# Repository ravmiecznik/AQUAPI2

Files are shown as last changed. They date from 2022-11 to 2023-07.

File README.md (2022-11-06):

# AQUAPI2

## Aquarium controller based on RaspberryPi Zero2 and Arduino.<br>
The controller supports:<br>

* PH control with use of <a href=https://botland.store/gravity-temperature-sensors/5874-dfrobot-gravity-ph-analog-sensormeter-5903351243513.html>DFORBOT PROBE</a>
and CO2 injection system equipped with CO2 electric valve
<br>
<p  align=center>

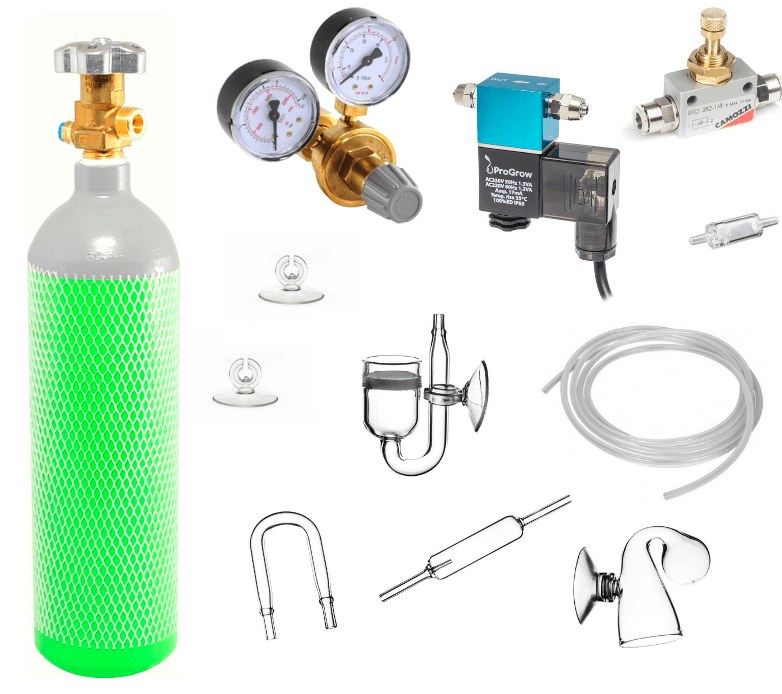
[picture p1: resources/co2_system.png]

</p>

* Temperature reading with DS12B20 digital thermometer sensor [<a href="https://www.circuitbasics.com/raspberry-pi-ds18b20-temperature-sensor-tutorial/">how to</a>] or any analog thermometer accessible via Arduino board

* Control devices and lighting with 8 channel Relay
<p align=center>
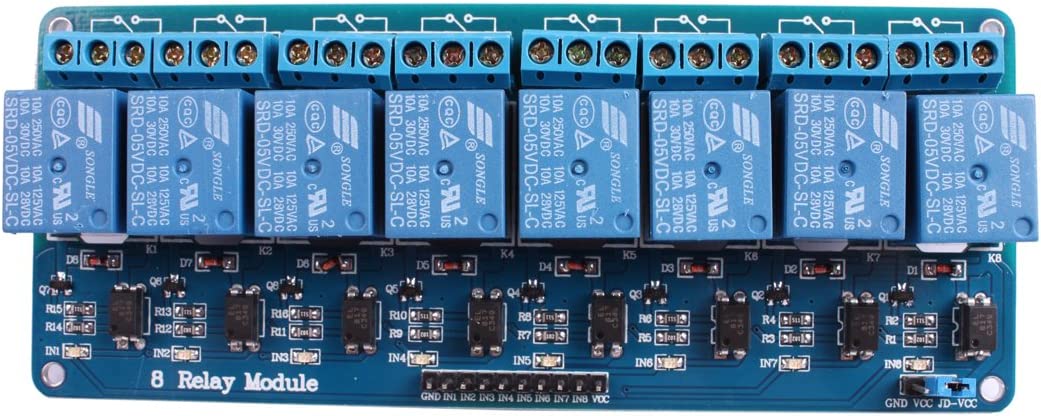
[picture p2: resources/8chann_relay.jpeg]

</p>

## Other components and software

* Arduino MINI PRO
<p  align=center>

</p>

* Arduino ISP programming done with RaspberryPI [<a href="https://learn.adafruit.com/program-an-avr-or-arduino-using-raspberry-pi-gpio-pins">Adafruit manual</a>]

* Plotly library <a href="https://plotly.com/python/">PLOTLY</a>
<p align=center>
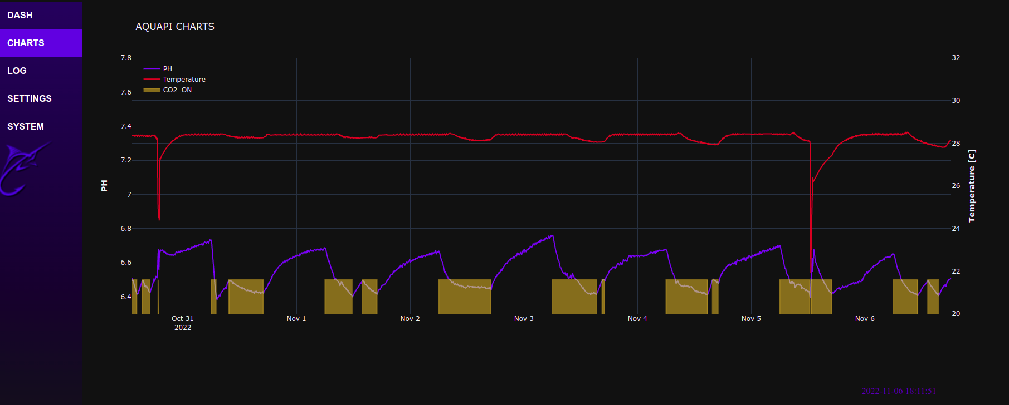
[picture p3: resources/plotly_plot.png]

</p>

* Circuit designed in Eagle [Version 0]

<p align=center>
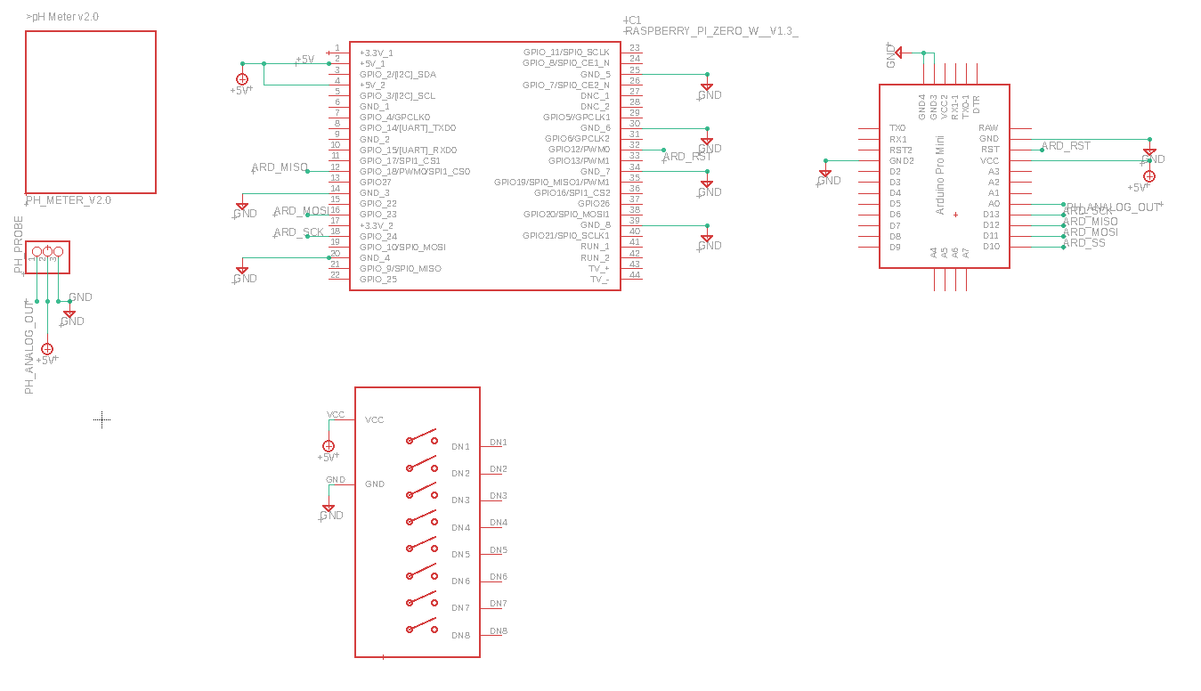
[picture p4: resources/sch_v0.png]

</p>

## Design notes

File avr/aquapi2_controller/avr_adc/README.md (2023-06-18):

### How to enable ADC
```C++
int main(void)
{
	Usart serial(get_usart_config());
	Serial = &serial;
	setup_stdout_for_printf();
	sei();

	{//auto remove temp variables in this scope

		bitfield8 adc_channels_ena;
		adc_channels_ena.b0 = 1;
		adc_channels_ena.b2 = 1;
        adc_channels_ena.b7 = 1;
		uint8_t samples_num = 3;
		Adc::enable_interrupt(adc_channels_ena, prescaler::div_128, vref::avcc_ext_cap, samples_num);
	}

	adc_results_s adc_results;
    while (true)
    {

    	Screen::clear();    //works when SCREEN is used on Linux
    	Screen::nl(20);
    	adc_results = Adc::get_adc_results();
    	printf("ADC1: %u\n\r", adc_results.adc0);
    	printf("ADC1: %u\n\r", adc_results.adc1);
    	printf("ADC2: %u\n\r", adc_results.adc2);
    	printf("ADC3: %u\n\r", adc_results.adc3);
    	printf("ADC4: %u\n\r", adc_results.adc4);
    	printf("ADC5: %u\n\r", adc_results.adc5);
    	printf("ADC6: %u\n\r", adc_results.adc6);
    	printf("ADC7: %u\n\r", adc_results.adc7);
    	printf("---------------------\n\r");

    	_delay_ms(500);
    }
}
```

### output 

```
---------------------
ADC1: 472
ADC1: 0
ADC2: 644
ADC3: 0
ADC4: 0
ADC5: 0
ADC6: 0
ADC7: 640
---------------------

```

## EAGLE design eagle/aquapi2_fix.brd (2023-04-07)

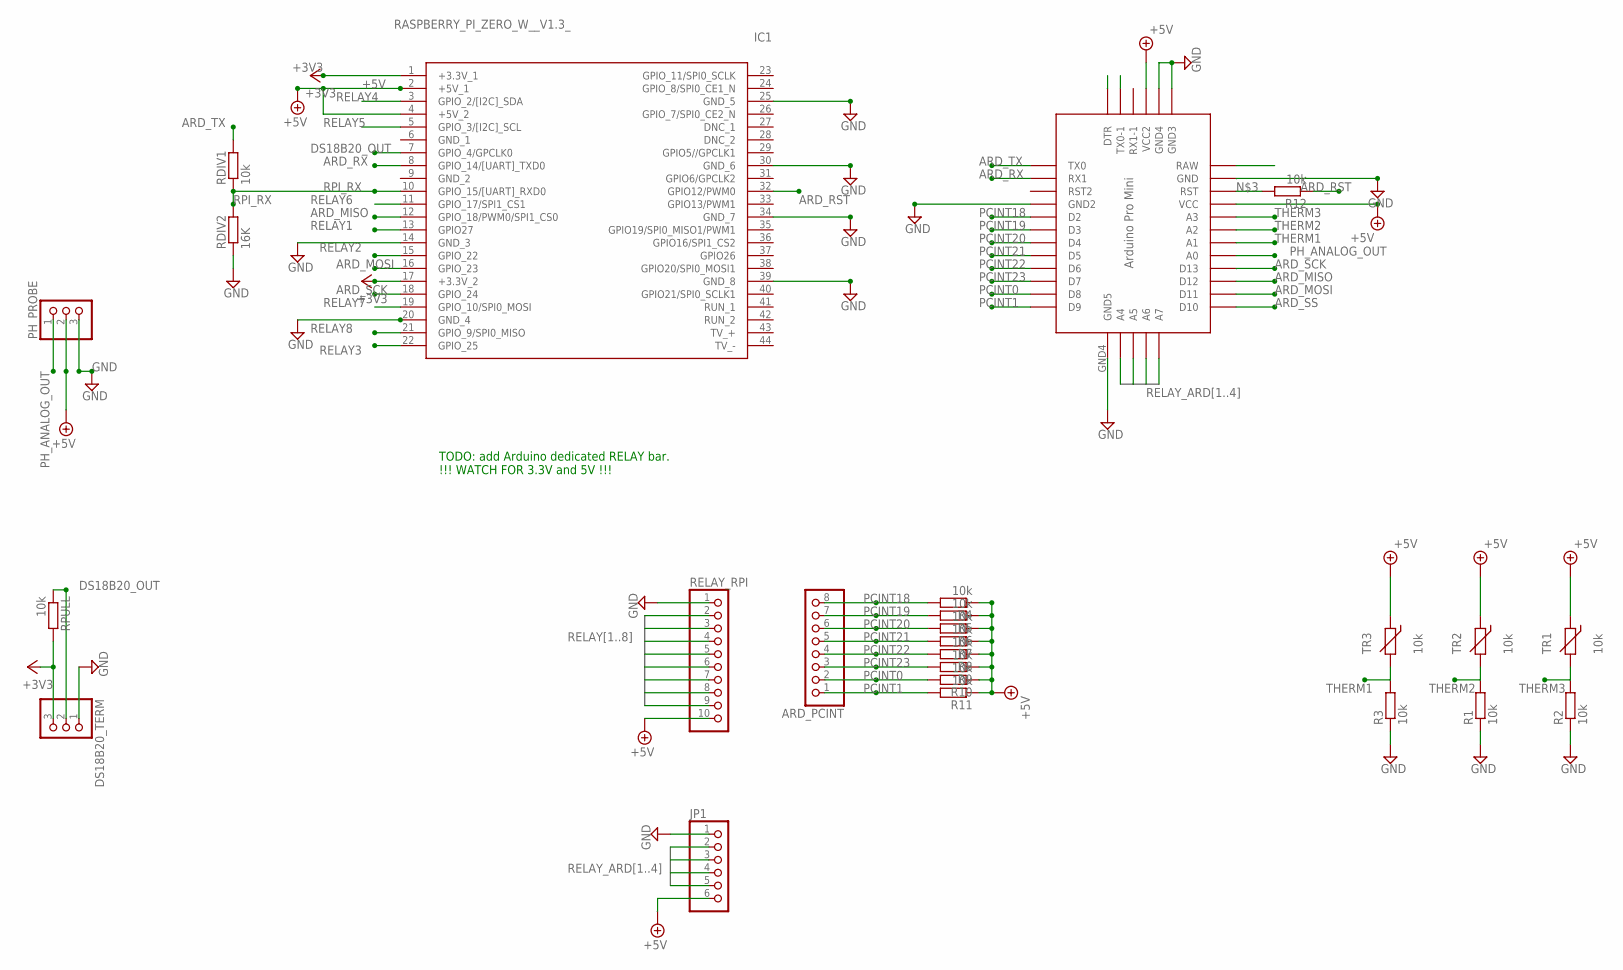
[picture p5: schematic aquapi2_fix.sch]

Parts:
ARD_PCINT: PINHD-1X8; 1X08
DS18B20_TERM: PINHD-1X3; 1X03
IC1: RASPBERRY_PI_ZERO_W__V1.3_; RASPBERRYPIZEROWV13
JP1: PINHD-1X6; 1X06
PH_PROBE: PINHD-1X3; 1X03
R1, R2, R3, R4, R5, R6, R7, R8, R9, R10, R11, R12: 10k; R0805
RDIV1: 10k; R0805
RDIV2: 16K; R0805
RELAY_RPI: PINHD-1X10; 1X10
RPULL: 10k; R0805
TR1, TR2, TR3: 10k; RS-2,5
U$2: PRO-MINI

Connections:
+3V3: DS18B20_TERM.3, IC1.1 (+3.3V_1), IC1.17 (+3.3V_2), RPULL.2
+5V: IC1.2 (+5V_1), IC1.4 (+5V_2), JP1.6, PH_PROBE.2, R4.1, R5.1, R6.1, R7.1, R8.1, R9.1, R10.1, R11.1, RELAY_RPI.10, TR1.1, TR2.1, TR3.1, U$2.VCC, U$2.VCC1 (VCC2)
ARD_MISO: IC1.12 (GPIO_18/PWM0/SPI1_CS0), U$2.D12
ARD_MOSI: IC1.16 (GPIO_23), U$2.D11
ARD_RST: IC1.32 (GPIO12/PWM0), R12.1
ARD_RX: IC1.8 (GPIO_14/[UART]_TXD0), U$2.RX1
ARD_SCK: IC1.18 (GPIO_24), U$2.D13
ARD_SS: U$2.D10
ARD_TX: RDIV1.2, U$2.TX0
DS18B20_OUT: DS18B20_TERM.2, IC1.7 (GPIO_4/GPCLK0), RPULL.1
GND: DS18B20_TERM.1, IC1.14 (GND_3), IC1.20 (GND_4), IC1.25 (GND_5), IC1.30 (GND_6), IC1.34 (GND_7), IC1.39 (GND_8), JP1.1, PH_PROBE.3, R1.1, R2.1, R3.1, RDIV2.1, RELAY_RPI.1, U$2.GND1 (GND2), U$2.GND2 (GND4), U$2.GND3, U$2.GND4 (GND5)
unnamed: R12.2, U$2.RST
PCINT0: ARD_PCINT.2, R10.2, U$2.D8
PCINT1: ARD_PCINT.1, R11.2, U$2.D9
PCINT18: ARD_PCINT.8, R4.2, U$2.D2
PCINT19: ARD_PCINT.7, R5.2, U$2.D3
PCINT20: ARD_PCINT.6, R6.2, U$2.D4
PCINT21: ARD_PCINT.5, R7.2, U$2.D5
PCINT22: ARD_PCINT.4, R8.2, U$2.D6
PCINT23: ARD_PCINT.3, R9.2, U$2.D7
PH_ANALOG_OUT: PH_PROBE.1, U$2.A0
RELAY1: IC1.13 (GPIO27), RELAY_RPI.2
RELAY2: IC1.15 (GPIO_22), RELAY_RPI.3
RELAY3: IC1.22 (GPIO_25), RELAY_RPI.4
RELAY4: IC1.3 (GPIO_2/[I2C]_SDA), RELAY_RPI.5
RELAY5: IC1.5 (GPIO_3/[I2C]_SCL), RELAY_RPI.6
RELAY6: IC1.11 (GPIO_17/SPI1_CS1), RELAY_RPI.7
RELAY7: IC1.19 (GPIO_10/SPI0_MOSI), RELAY_RPI.8
RELAY8: IC1.21 (GPIO_9/SPI0_MISO), RELAY_RPI.9
RELAY_ARD1: JP1.2, U$2.A4
RELAY_ARD2: JP1.3, U$2.A5
RELAY_ARD3: JP1.4, U$2.A6
RELAY_ARD4: JP1.5, U$2.A7
RPI_RX: IC1.10 (GPIO_15/[UART]_RXD0), RDIV1.1, RDIV2.2
THERM1: R3.2, TR3.2, U$2.A1
THERM2: R1.2, TR2.2, U$2.A2
THERM3: R2.2, TR1.2, U$2.A3

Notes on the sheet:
TODO: add Arduino dedicated RELAY bar. !!! WATCH FOR 3.3V and 5V !!!

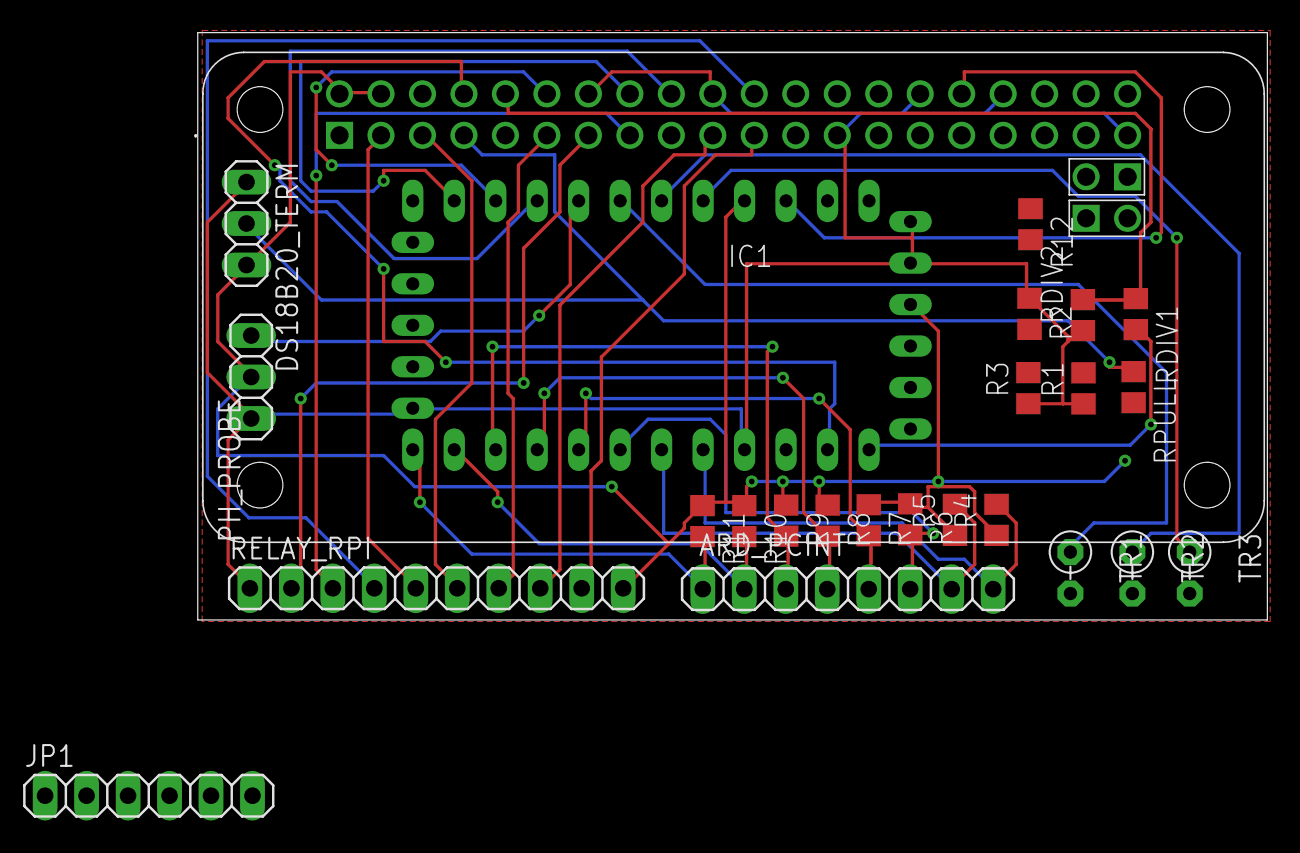
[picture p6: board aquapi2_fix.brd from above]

Board: 2 copper layers, 65.5 x 36.0 mm, 25 parts (1 on the bottom side), 36 nets.

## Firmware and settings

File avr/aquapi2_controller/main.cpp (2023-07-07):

/*
 * main.cpp
 *
 *  Created on: Dec 23, 2022
 *      Author: rafal
 */
#include <avr/io.h>
#include <util/delay.h>
#include <avr/interrupt.h>
#include <avr/pgmspace.h>
#include <stdio.h>
#include <assert.h>

#include "atm_timer/atm_timer16bit.h"
#include "usart/usart.h"
#include "avr_adc/avr_adc.h"
#include "avr_screen/screen.h"



Usart* Serial;

//experimental
void* operator new(size_t, void* p) {return p;};
void* operator new(size_t s) {return malloc(s);};
void operator delete(void* ptr) {free(ptr);};


/****************************************************************/
/*
 * Configuration of standard output for functions printf, printf_p and so on
 */
static int put(char c, FILE *stream){
	Serial->Putchar(c);
	return 0;
}
static FILE uartout = {0};
void setup_stdout_for_printf(){
	fdev_setup_stream(&uartout, put, NULL, _FDEV_SETUP_WRITE);
	stdout = &uartout;
	stderr = &uartout;
}
/****************************************************************/

UsartConfig get_usart_config(){
	UsartConfig uc;
	uc.baud = 9600;
	uc.rx_buffer_size = 50;
	uc.tx_buffer_size = 500;
	uc.u_num = usart_num::usart0;
	return uc;
}

#define DELAY 500

using namespace adc;
using namespace timer;




int main(void)
{
	Usart serial(get_usart_config());
	Serial = &serial;
	setup_stdout_for_printf();
	sei();

	Timer1 timer1_16bit(ClockSelection::clk_d1);
	Time init_time{12, 29, 30, 0};

	auto tic = timer1_16bit.tic();
    while (true)
    {

    	Screen::get_input(serial);
    	Screen::set_text_color(Screen::text_color::green);
    	Screen::clear();
    	Screen::mv_cursor(50);
    	auto now = timer1_16bit.get_time(init_time);
    	printf("time %02um:%02us\n\r", now.minutes , now.seconds);
    	printf("---------------------\n\r");
    	tic = timer1_16bit.tic();
    	_delay_ms(500);
    }
}

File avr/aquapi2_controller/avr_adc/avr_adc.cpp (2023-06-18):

/*
 * registers.cpp
 *
 *  Created on: Mar 27, 2023
 *      Author: rafal
 */

#include <avr/interrupt.h>
#include <avr/delay.h>
#include <avr/io.h>
#include <stdarg.h>
#include <stdio.h>
#include "avr_adc.h"
#include "../common/common.h"



namespace adc {
	constexpr static uint8_t CHANNELS_NUM = 8;
	volatile uint16_t ADC_results[CHANNELS_NUM];


	/*
	 * define registers as generic_register unions
	 */

	auto& admux_r_descr		= to_register_descriptor<admux_s>(ADMUX);
	auto& adcsra_r_descr 	= to_register_descriptor<adcsra_s>(ADCSRA);
	auto& adcsrb_r_descr 	= to_register_descriptor<adcsrb_s>(ADCSRB);
	auto& didr0_r_descr 	= to_register_descriptor<didr0_s>(DIDR0);
	auto& prr_r_descr 		= to_register_descriptor<prr_s>(PRR);


	/*
	 * Interface to access bitfields of registers
	 */
	admux_s& admux 		= admux_r_descr.bitfield;
	adcsra_s& adcsra 	= adcsra_r_descr.bitfield;
	adcsrb_s& adcsrb 	= adcsrb_r_descr.bitfield;
	didr0_s& didr0 		= didr0_r_descr.bitfield;
	prr_s& prr 			= prr_r_descr.bitfield;

	/*
	 * Default ADC interrupt handler
	 */
	volatile static uint8_t current_sample = 0;
	volatile static uint32_t samples_sum = 0;
	ISR(ADC_vect){
		if(current_sample++ < Adc::get_samples_num()){
			samples_sum += ADC-1;
		}
		else{
			ADC_results[Adc::get_current_channel()] = samples_sum/Adc::get_samples_num();
			Adc::advance_channel();
			current_sample = 0;
			samples_sum = 0;
		}
		adcsra.adie = 1;
		adcsra.adsc = 1;
	}

	/*
	 * Enable ADC
	 */
	void Adc::enable(vref ref) {
		adcsra.aden = 1;
		prr.pradc = 0;
		admux.refs = (uint8_t)ref;
	}

	/*
	 * Enables ADC interrupt
	 */
	void Adc::enable_interrupt(bitfield8 channels_bitmask, prescaler prescaler, vref v, uint8_t samples){
		select_channels(channels_bitmask);
		Assert(channels_bitmask);	//must use Adc::select_channels first
		samples_num = samples;
		adcsra.aden = 1;
		admux.refs = (uint8_t)v;
		adcsra.adps = (uint8_t)prescaler;
		adcsra.adie = 1;
		enable(v);

		adcsra.adsc = 1;
		delay_cpu_cycles(5);
	}

	/*
	 * Start single ADC conversion
	 */
	void Adc::start_adc(uint8_t mux) {
		uint8_t didr_old = didr0_r_descr;
		didr0_r_descr.set_bit(mux);
		admux.mux = mux;
		adcsra.adsc = 1;
		delay_cpu_cycles(5);
		didr0_r_descr = didr_old;
		while(adcsra.adsc == 1);
	}

	/*
	 * Start and get single ADC conversion
	 */
	uint16_t Adc::get_adc(uint8_t mux, uint16_t samples) {
		uint16_t sum = 0;
		Assert(samples < ( (1<<8*(sizeof(uint16_t) - sizeof(uint8_t))) -1 )); // overflow protection
		start_adc(mux);	// one blind ADC conversion to clean last result;
		for(uint8_t i=0; i<samples; ++i){
			start_adc(mux);
			sum += ADC;
			ADC = 0;
		}
		return sum/samples;

	}

	/*
	 * Select channels for ADC
	 */
	void Adc::select_channels(uint8_t bitmask){
		didr0_r_descr |= bitmask;	// disable digital function of pins ADC5..0
		channels_bitmask |= bitmask;
	}

	/*
	 * Select single channel for ADC
	 */
	void Adc::select_channel(uint8_t chann){
		didr0_r_descr |= (1<<chann);
		channels_bitmask |= (1<<chann);
		current_channel = chann;
		DDRC &= ~(1<<chann); 	// should be solved by pull-up resistor
		PORTC |= (1<<chann);		// should be solved by pull-up resistor
	}


	/*
	 * Get adc_results_s struct
	 */
	adc_results_s Adc::get_adc_results(){
		return (adc_results_s&)(*adc_results);
	}

	adc_results_s* Adc::get_adc_resultsp(){
		return (adc_results_s*)adc_results;
	}

	void Adc::advance_channel(){
		while((Adc::channels_bitmask & (1<<current_channel++)) == 0){
			current_channel %= CHANNELS_NUM;
		}
		admux.mux = Adc::get_current_channel();
	}

	volatile uint8_t Adc::channels_bitmask = 0;
	uint8_t Adc::didr_old = 0;
	volatile uint8_t Adc::current_channel = 0;
	volatile uint8_t Adc::samples_num = 1;
	volatile uint16_t* Adc::adc_results = ADC_results;
}

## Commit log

2022-11-06 init commit
    [aquapi2.brd, aquapi2.sch]
2022-11-06 relayx8 lib added
    [aquapi2.brd, aquapi2.sch]
2022-11-06 schemtic added
    [aquapi2.brd, aquapi2.sch]
2022-11-06 bigger schematic
2022-11-06 relay pic
2022-11-06 arudino device lib fixed
    [aquapi2.brd, aquapi2.sch]
2023-03-28 Squashed commit of the following:
    commit 7dce77e1b018337bae77b73dfeb2fe2afd6dd7fb
    Author: rafal <ravmiecznk@gmail.com>
    Date: Mon Mar 27 18:15:28 2023 +0200
    new constructor from struct
    commit 8f6d84a0210c76b2bc0acb519426c939a0a5c33f
    Author: rafal <ravmiecznk@gmail.com>
    Date: Mon Mar 27 18:13:10 2023 +0200
    usart draft works
    commit a12afc0a744ad612be8265cef467c83d1d3cefab
    Author: rafal <ravmiecznk@gmail.com>
    Date: Mon Mar 27 17:49:51 2023 +0200
    schematic fix
    commit a0211998f02243aec53f4161e691c0fde81374dd
    Author: rafal <ravmiecznk@gmail.com>
    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
    [aquapi2.brd, aquapi2.sch]
2023-04-07 Squashed commit of the following:
    cmd line POC
    commit 337e95aa13cad48c1064047ce5c9ad90a4095ac0
    Date: Fri Apr 7 17:02:08 2023 +0200
    poc works
    commit 96e2bba8cf86e2d1e8c289a96239566a88c918fa
    Date: Wed Mar 29 14:14:44 2023 +0200
    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
    [aquapi2_fix.brd, aquapi2_fix.sch]
2023-04-08 Timer1 can be started
2023-06-17 init version of timers, terminal support POC
2023-06-17 bug fix: adc rosult stored sum instead of mean
    [avr_adc.cpp, main.cpp]
2023-06-18 fix for ADC interrupt enable, fix for 'leaking' ADC results to adjacent ports
    [avr_adc.cpp, main.cpp]
2023-06-18 short ADC description added
2023-07-07 Squashed commit of the following:
    commit 798ce41465e0510e75b4520c080c88b3ab18497c
    Date: Fri Jul 7 14:03:10 2023 +0200
    use microseconds to improve timer accuracy, elimates increasing timer error over time
    commit b00f4a703aaf7847080440523ae8438c521330d4
    Date: Fri Jul 7 10:52:19 2023 +0200
    Timer can measure tic-toc
    commit 69b4a89fb3e4e1dabbc498e2244a4e420cdebe27
    Date: Fri Jul 7 10:45:17 2023 +0200
    TicToc object added to timer, timer can measure tic-toc
    commit 207d85f06c9d2ca03eec03d237bf7c043634b374
    Date: Fri Jul 7 10:44:15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
    [atm_timer16bit.h, main.cpp]
